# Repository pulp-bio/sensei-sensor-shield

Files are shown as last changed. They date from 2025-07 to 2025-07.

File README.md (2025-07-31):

# SENSEI Sensor Shield

This repository contains the hardware design files for the **SENSEI Sensor Shield**, a versatile extension developed as part of the **Urban Twin** project. The sensor shield integrates multiple sensors for environmental monitoring and is designed to work seamlessly with the [SENSEI Base Board](https://github.com/pulp-bio/sensei-base-board), offering advanced data collection capabilities for urban sensing and other applications.

## Overview

The **SENSEI Sensor Shield** is an extension board designed to support a wide range of sensors for environmental data acquisition. It can be used in urban monitoring scenarios, including air quality monitoring, light sensing, and structural health diagnostics. Developed under the **Urban Twin** project, it is built for flexibility and long-term deployment, making it ideal for multi-sensor applications.

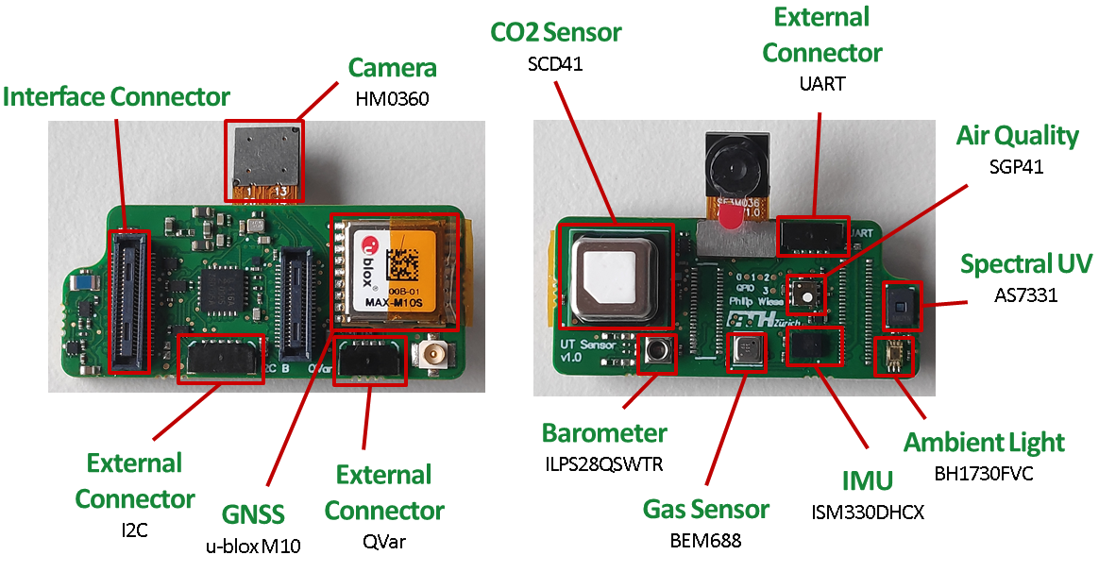
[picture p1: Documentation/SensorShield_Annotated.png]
SENSEI Sensor Shield


### Key Features
- **Optical Sensors**:
  - **Ultraviolet (UVA, UVB, UVC)** sensing.
  - **Infrared and Visual light** sensing.
  - **Camera (HM0360)**: 640 x 480 resolution at 60 fps.

- **Environmental Sensors**:
  - **CO2 Sensor (SCD41)**.
  - **Air Quality Sensor (SGP41)**.
  - **Barometer (ILPS28QSWTR)**.
  - **Gas Sensor (BME688)**.
  - **Quasi-Electrostatic Potential (QVar)** for detecting potential changes.

- **Position/IMU Sensors**:
  - **IMU (ISM330DHCX)**: Advanced 6 DOF sensor for motion tracking and vibration analysis.
  - **GNSS (u-blox M10)** for accurate geolocation.

- **External Connectors**:
  - **I2C, UART**, and **GPIO** for seamless integration of additional peripherals.

### Software Development Kit (SDK)
The **SENSEI SDK** provides software support for both the **SENSEI Base Board** and the **SENSEI Sensor Shield**. It includes sensor drivers, power management, and communication tasks to facilitate data collection and processing. The SDK is available at [SENSEI SDK Repository](https://github.com/pulp-bio/sensei-sdk).

### Demo Applications
- YOLOv5 Occupancy Detection: https://github.com/pulp-bio/sensei-demo-yolov5
- Sensor Readout: https://github.com/pulp-bio/sensei-demo-sensorhub

## Changelog
A detailed changelog is available in the [Changelog.md](Changelog.md) file, which tracks all major updates and revisions to the board's design and documentation.

## Contributors
- **Philip Wiese** ([wiesep@iis.ee.ethz.ch](mailto:wiesep@iis.ee.ethz.ch))
- **Sebastian Frey** ([sefrey@iis.ee.ethz.ch](mailto:sefrey@iis.ee.ethz.ch))

## Publications

If you use the SENSEI Sensor Shield in your work or research, you can cite us with:

### COINS 2025: A Multi-Modal IoT Node for Energy-Efficient Environmental Monitoring with Edge AI Processing
```
@misc{wiese2025multimodaliotnodeenergyefficient,
      title={A Multi-Modal IoT Node for Energy-Efficient Environmental Monitoring with Edge AI Processing},
      author={Philip Wiese and Victor Kartsch and Marco Guermandi and Luca Benini},
      year={2025},
      eprint={2507.14165},
      archivePrefix={arXiv},
      primaryClass={eess.SP},
      url={https://arxiv.org/abs/2507.14165},
}
```
This paper has been accepted at 2025 IEEE International Conference on Omni-layer Intelligent Systems (COINS) and the preprint is available on arXiv @ [arXiv:2507.14165](https://arxiv.org/abs/2507.14165).

### SENSEI Paper
```
TBD
```

## License
This repository makes use of two licenses:
- for all *software*: Apache License Version 2.0
- for all *hardware*: Solderpad Hardware License Version 0.51

For further information have a look at the license files: `LICENSE.hw`, `LICENSE.sw`

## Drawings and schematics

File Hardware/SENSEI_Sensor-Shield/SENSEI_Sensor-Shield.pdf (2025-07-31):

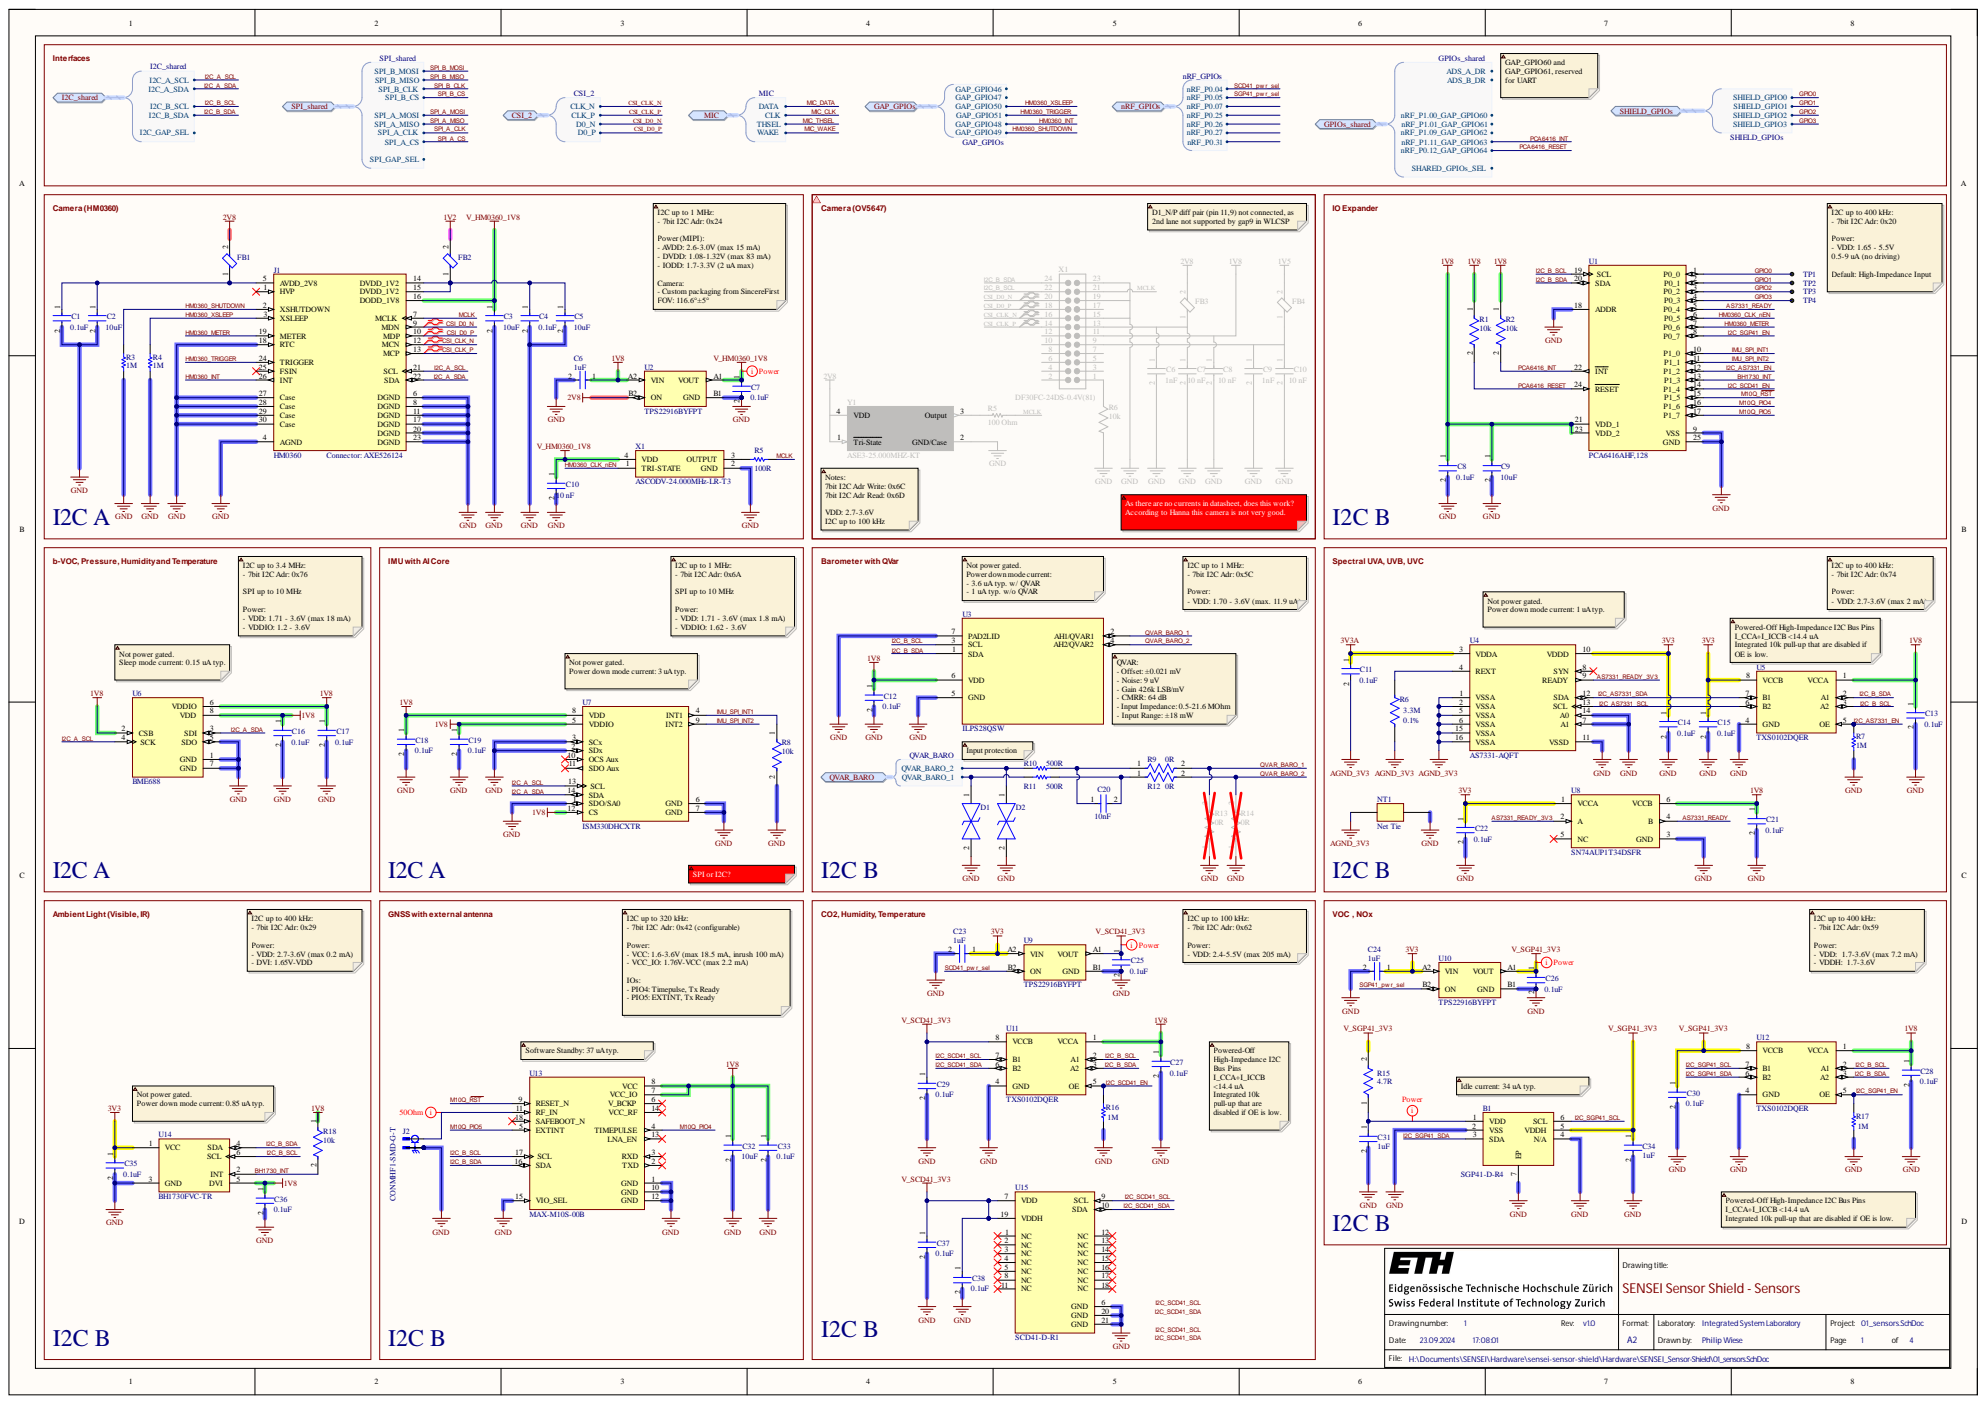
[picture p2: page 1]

D1_N/P diff pair (pin 11,9) not connected, as
2nd lane not supported by gap9 in WLCSP

Default: High-Impedance Input

Camera:
- Custom packaging from SincereFirst
FOV: 116.6°±5°

As there are no currents in datasheet, does this work?
According to Hanna this camera is not very good.

b-VOC, Pressure, Humidityand Temperature

IMU with AI Core

Not power gated.
Power down mode current:
- 3.6 uA typ. w/ QVAR
- 1 uA typ. w/o QVAR

Spectral UVA, UVB, UVC

SPI up to 10 MHz

Power down mode current: 1 uAtyp.

Powered-Off High-Impedance I2C Bus Pins
I_CCA+I_ICCB <14.4 uA
Integrated 10k pull-up that are disabled if
OE is low.

Sleep mode current: 0.15 uA typ.

Power down mode current: 3 uAtyp.

Ambient Light (Visible, IR)

Power:
- VCC: 1.6-3.6V (max 18.5 mA, inrush 100 mA)
- VCC_IO: 1.76V-VCC (max 2.2 mA)

Idle current: 34 uA typ.

Power down mode current: 0.85 uAtyp.

disabled if OE is low.

Integrated 10k pull-up that are disabled if OE is low.

Drawing title:
SENSEI Sensor Shield - Sensors

File:
H:\Documents\SENSEI\Hardware\sensei-sensor-shield\Hardware\SENSEI_Sensor-Shield\01_sensors.SchDoc

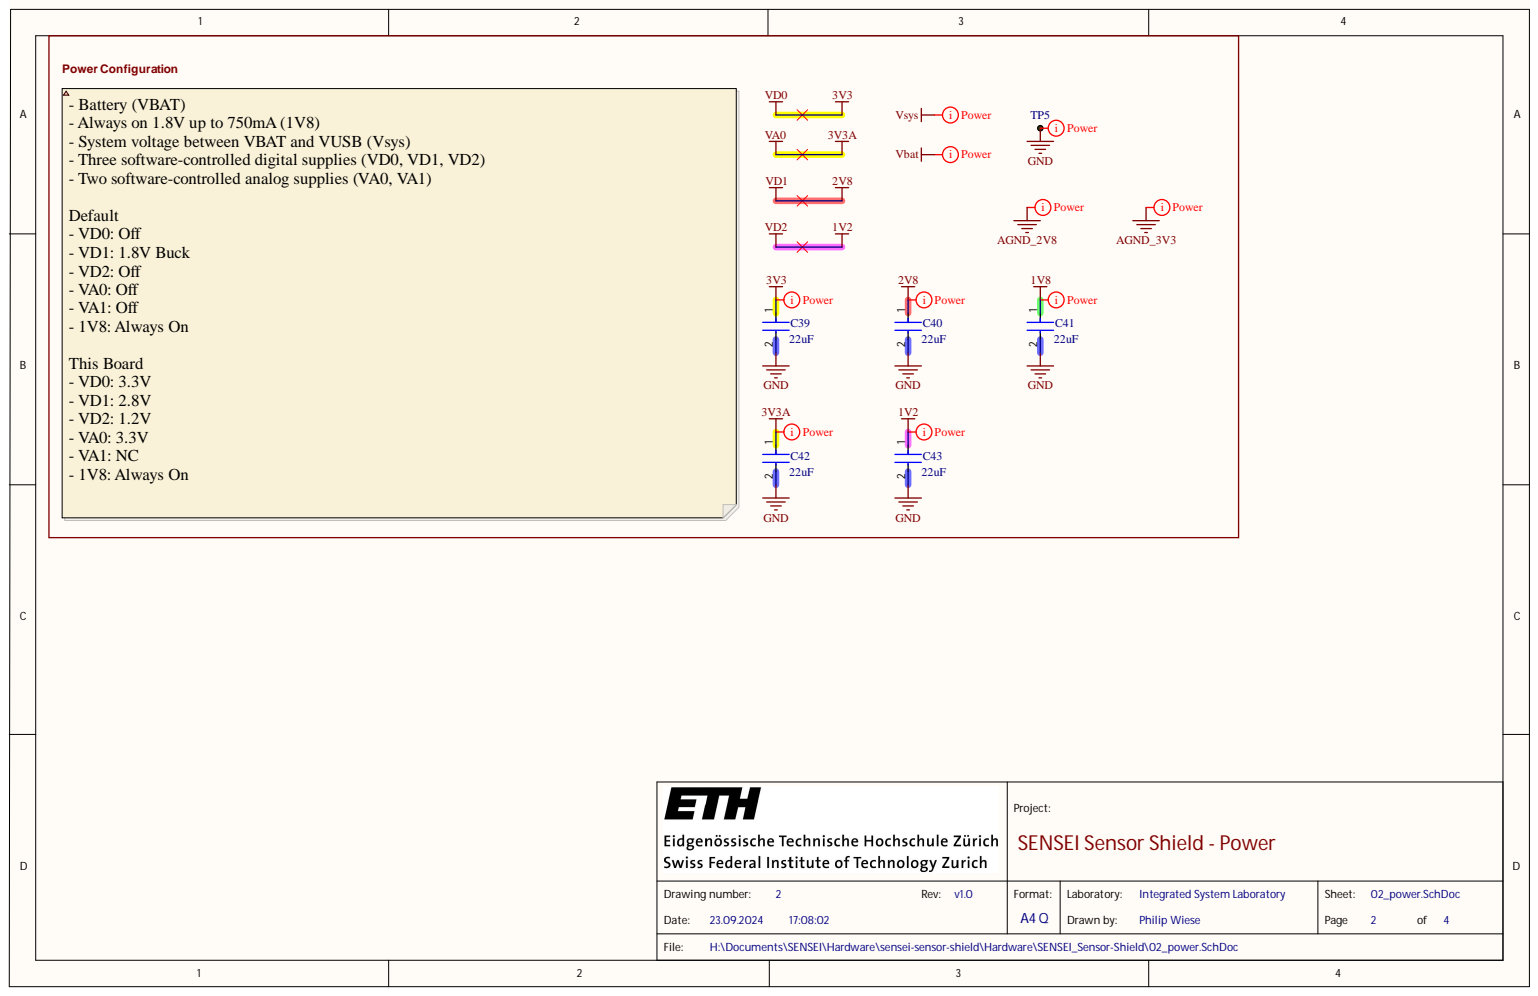
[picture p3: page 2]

- Battery (VBAT)
- Always on 1.8V up to 750mA (1V8)
- System voltage between VBAT and VUSB (Vsys)
- Three software-controlled digital supplies (VD0, VD1, VD2)
- Two software-controlled analog supplies (VA0, VA1)

Project: SENSEI Sensor Shield - Power

Drawing number: 2 Rev: v1.0 Date: 23.09.2024 17:08:02 | Format: A4 Q | Laboratory: Integrated System Laboratory Drawn by: Philip Wiese | Sheet: 02_power.SchDoc Page 2 of 4

H:\Documents\SENSEI\Hardware\sensei-sensor-shield\Hardware\SENSEI_Sensor-Shield\02_power.SchDoc

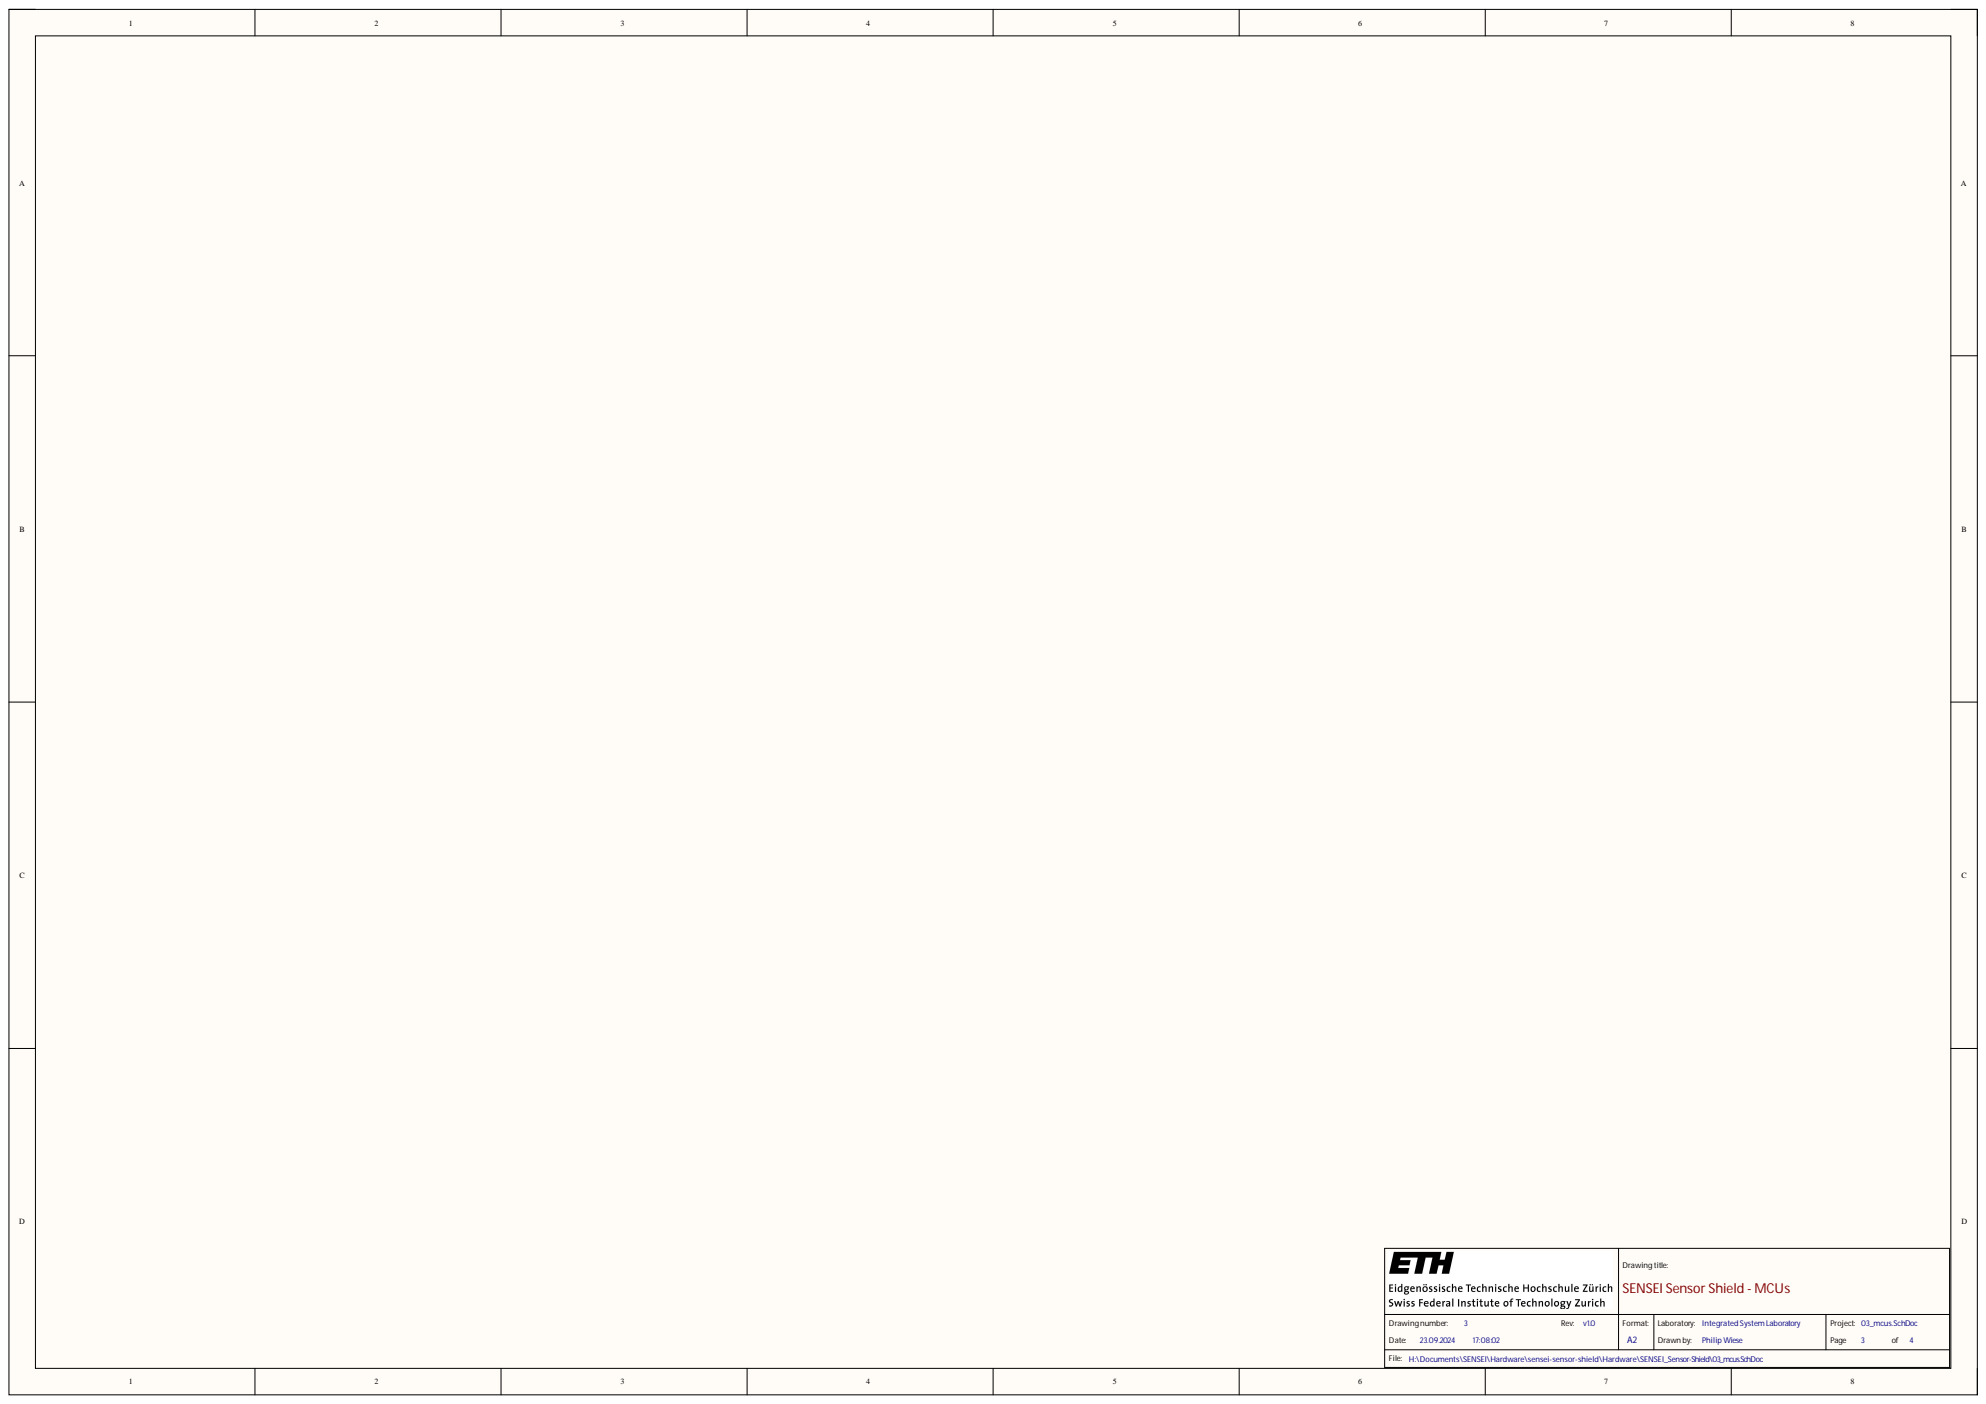
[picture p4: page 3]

Drawing title: SENSEI Sensor Shield - MCUs

17:08:02 | A2 | Laboratory: Integrated SystemLaboratory PhilipWiese | Project: 03_mcus.SchDoc Page 3 of 4

H:\Documents\SENSEI\Hardware\sensei-sensor-shield\Hardware\SENSEI_Sensor-Shield\03_mcus.SchDoc

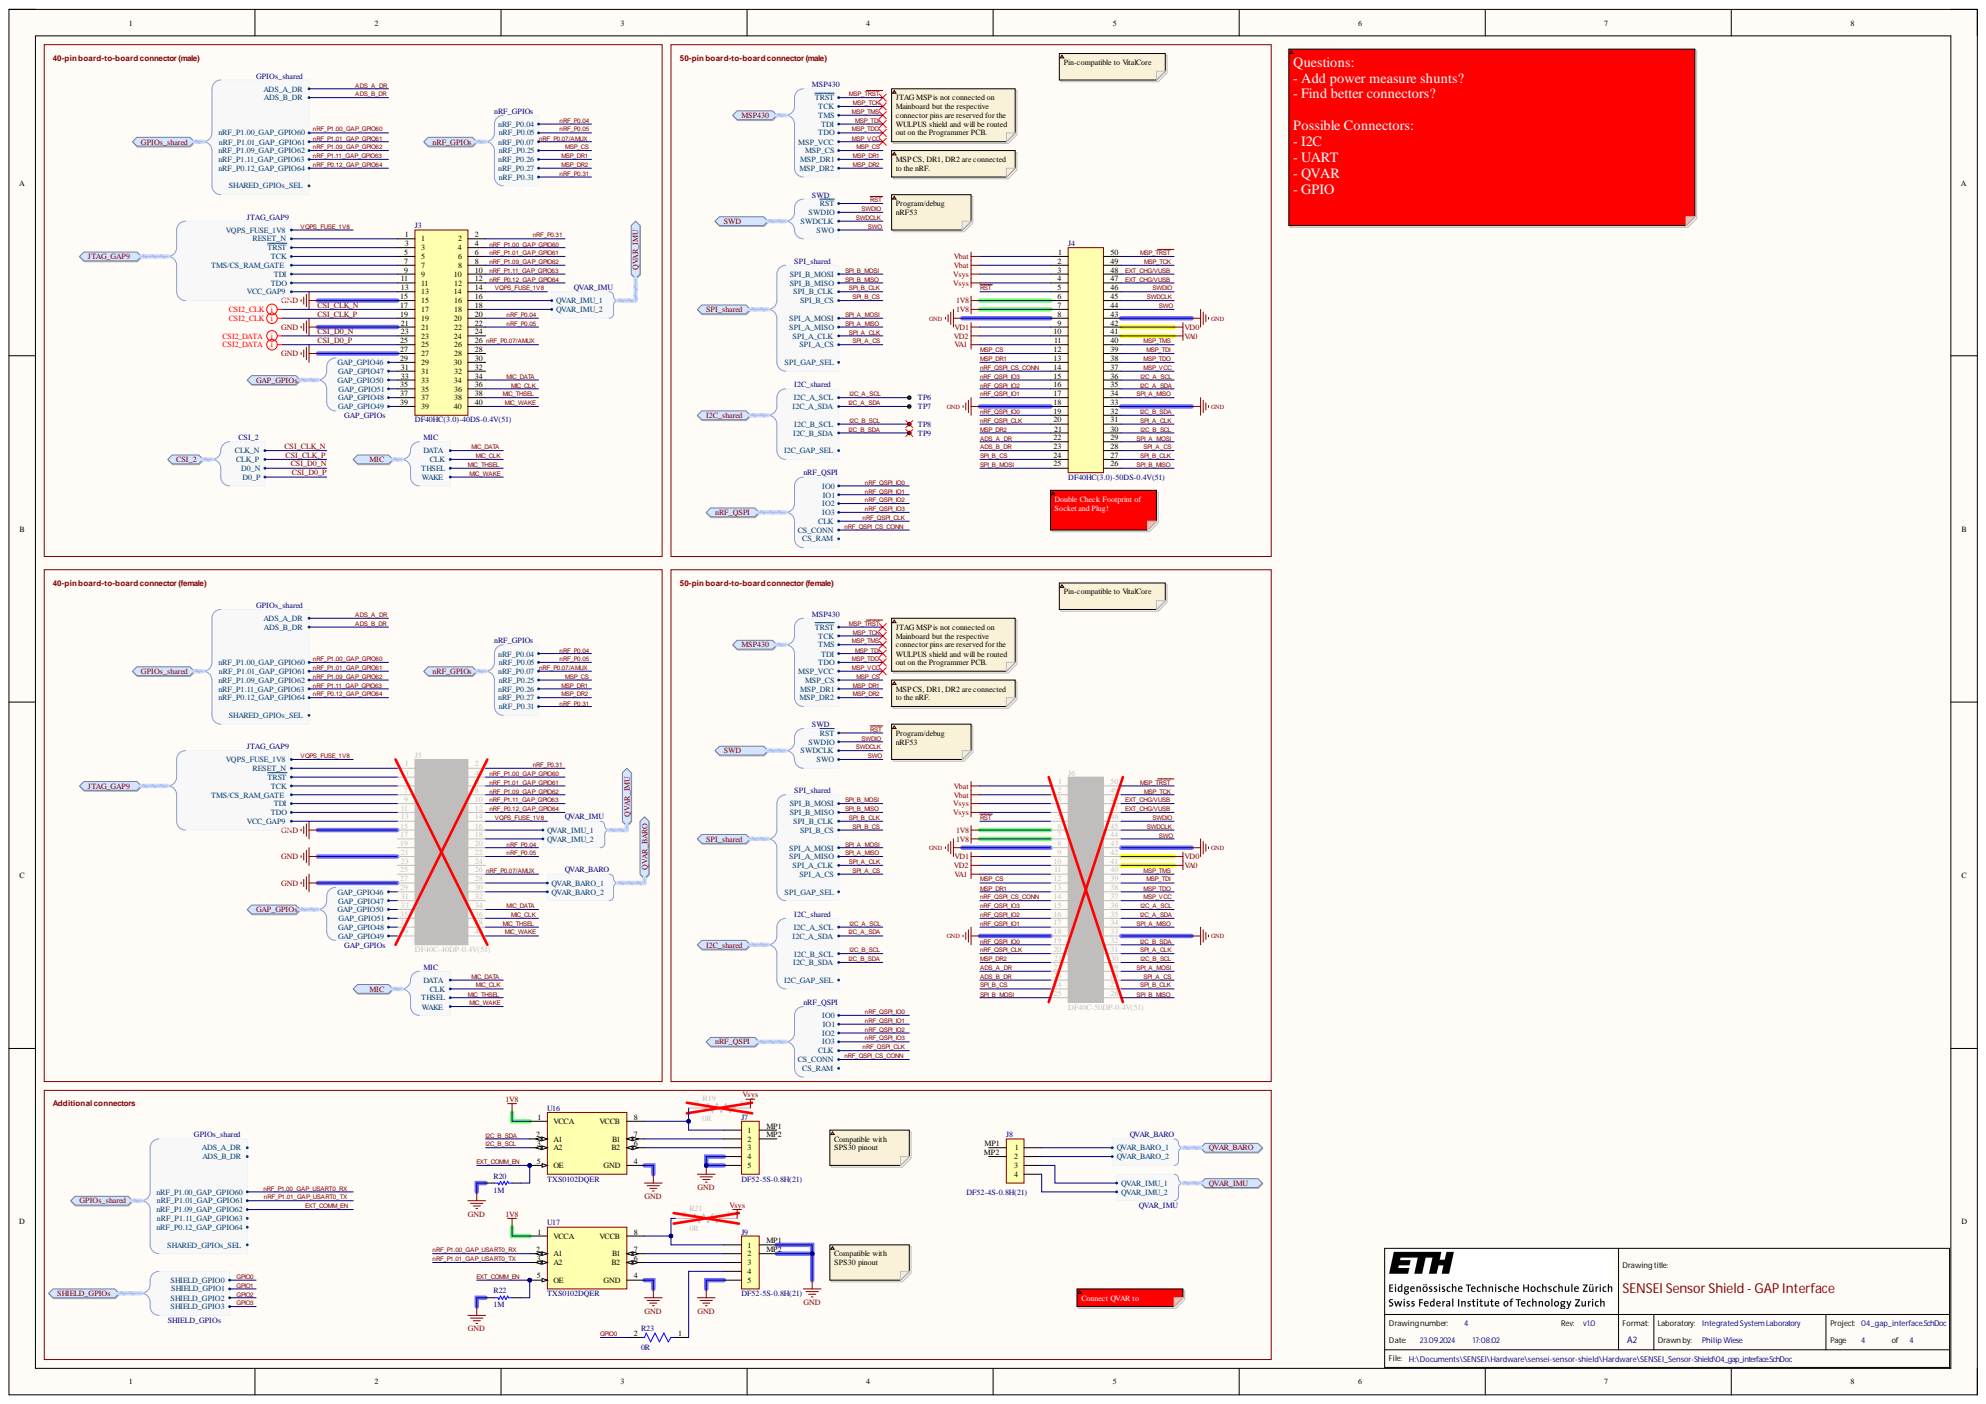
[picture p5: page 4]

40-pin board-to-board connector(male)

50-pin board-to-board connector(male)

Pin-compatible to VitalCore

Questions:
- Add power measure shunts?
- Find better connectors?

JTAG MSP is not connected on
Mainboard but the respective
connector pins are reserved for the
WULPUS shield and will be routed
out on the Programmer PCB.

Double Check Footprint of
Socket and Plug!

Drawing title:
SENSEI Sensor Shield - GAP Interface

H:\Documents\SENSEI\Hardware\sensei-sensor-shield\Hardware\SENSEI_Sensor-Shield\04_gap_interface.SchDoc

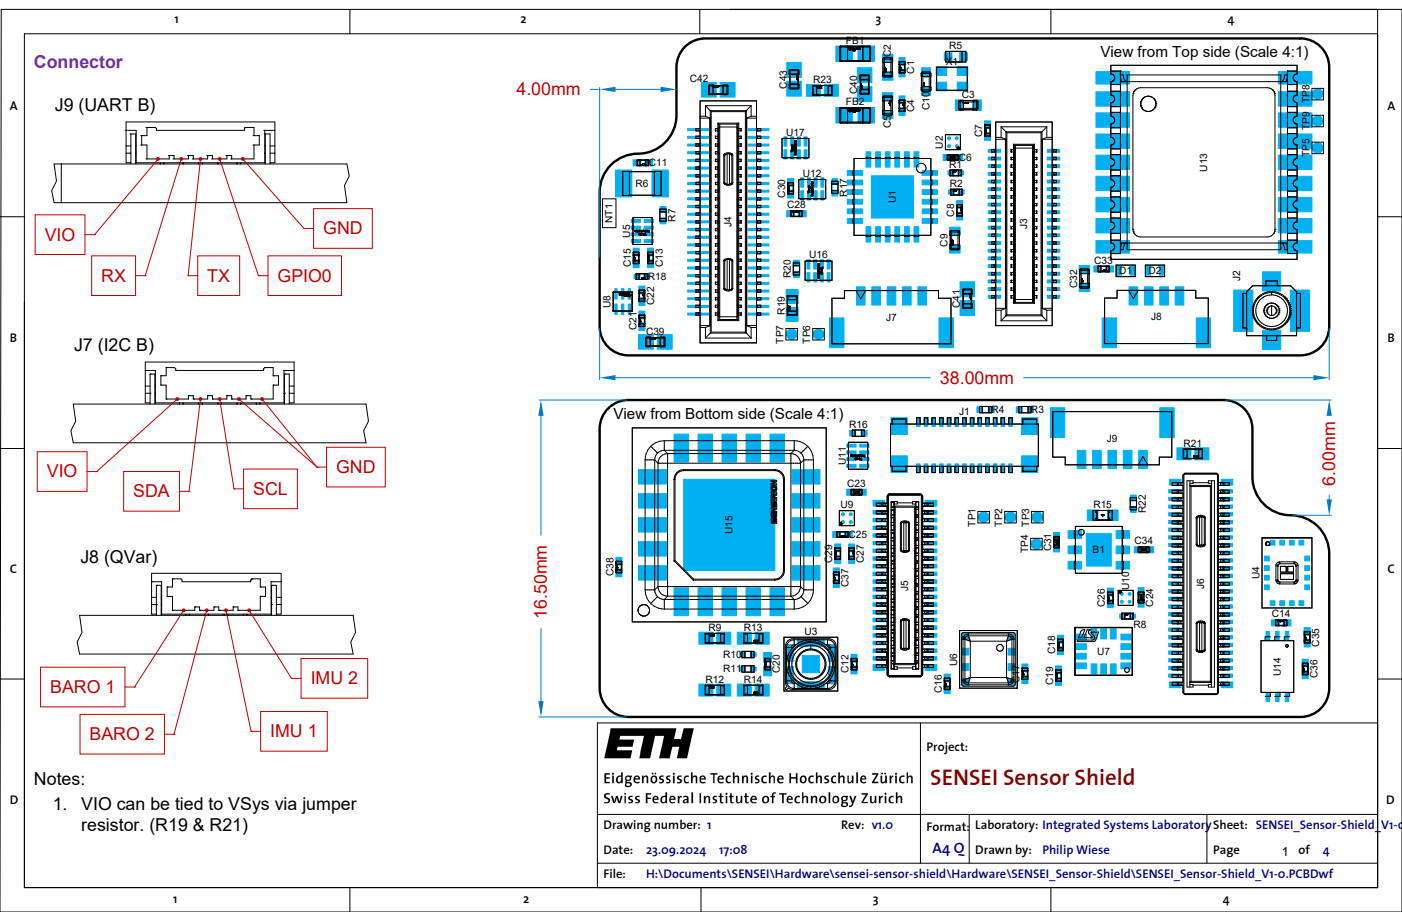
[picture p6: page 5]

View from Top side (Scale 4:1)

View from Bottom side (Scale 4:1)

VIO can be tied to VSys via jumper

Laboratory: Integrated Systems Laboratory

H:\Documents\SENSEI\Hardware\sensei-sensor-shield\Hardware\SENSEI_Sensor-Shield\SENSEI_Sensor-Shield_V1-0.PCBDwf

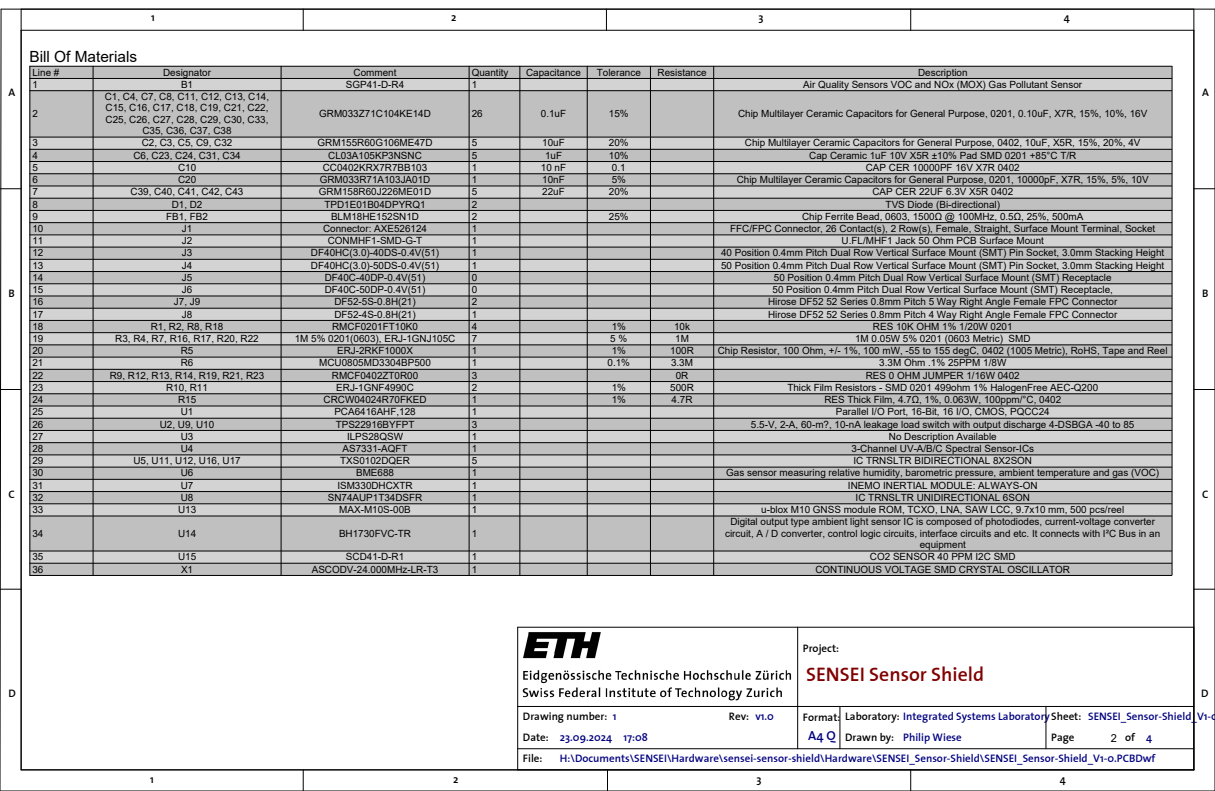
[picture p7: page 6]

Line # | Designator | Comment | Quantity | Capacitance | Tolerance | Resistance | Description
1 | B1 | SGP41-D-R4 | 1 | | | | Air Quality Sensors VOC and NOx (MOX) Gas Pollutant Sensor
2 | C1, C4, C7, C8, C11, C12, C13, C14, C15, C16, C17, C18, C19, C21, C22, C25, C26, C27, C28, C29, C30, C33, C35, C36, C37, C38 | GRM033Z71C104KE14D | 26 | 0.1uF | 15% | | Chip Multilayer Ceramic Capacitors for General Purpose, 0201, 0.10uF, X7R, 15%, 10%, 16V

3 | C2, C3, C5, C9, C32 | GRM155R60G106ME47D | 5 | 10uF | 20% | | Chip Multilayer Ceramic Capacitors for General Purpose, 0402, 10uF, X5R, 15%, 20%, 4V
4 | C6, C23, C24, C31, C34 | CL03A105KP3NSNC | 5 | 1uF | 10% | | Cap Ceramic 1uF 10V X5R ±10% Pad SMD 0201 +85°C T/R
5 | C10 | CC0402KRX7R7BB103 | 1 | 10 nF | 0.1 | | CAP CER 10000PF 16V X7R 0402
6 | C20 | GRM033R71A103JA01D | 1 | 10nF | 5% | | Chip Multilayer Ceramic Capacitors for General Purpose, 0201, 10000pF, X7R, 15%, 5%, 10V
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

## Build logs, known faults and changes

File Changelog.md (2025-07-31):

# Changelog

## Version 1.1 (unreleased)
- 

## Version 1.0 (23.09.24)
- Inital Version

## Version 0.2 - PCB Review (02.04.24)
- [General] Switched to an 8 Layer PCB with more GND planes
- [Via] Switched from 0.1/0.3mm vias to 0.2/0.4mm
- [GPS] Added 50 Ohm single-ended impedance matching for antenna
- [Camera] Connect XShutDown and XSleep directly to GAP9
- [Camera] Connect CLK Enable to IO expander instead of directly to XShutDown
- [Camera] Added load switch to separately control 1.8V
- [Camera] Removed the AGND to make the PCB more feasible
- [Connector] Connected VIO to VSys via zero-ohm resistor (UART & I2C)
- [Board] Increase the vertical board size by 1mm (0.5mm on both sides)

### Open comments
#### Julian
> I see in the datasheet, that you might need to sequence XShutDown and XSleep such that the camera can start up. You can access both pins IOs via GPIOs and expander but if you need the camera a lot, it might be worth adding a sequencer.

I want to try to keep the complexity (number of components and "automation") as low as possible. Hence, I connect XShutDown and XSleep directly to GAP9, which allows proper manual sequencing. In case there is some room for optimization, I will tackle this in the second iteration.

> I see the HM0360_Int and HM0360_trigger are directly connected to gap_gpios, I directly connected only HM0360_trigger and sleep, and the interrupt seemed for me to uninteresting (look at the datasheet if the interrupt pin of the camera really is what you think... for me seemed not...)

I am interested in the ALC (Illumination Change) and MD (Motion Detection) features.

> Why do you use the hm0360_shutdown pin to turn on the external oscillator... in the timing sequence of the camera the clock was already running, I'm not sure if this could lead to troubles if you want to repurpose the shutdown pin for turning on the osci, just check please

Good point! I connect CLK Enable to the IO expander instead of directly to XShutDown. As the default IO configuration is high-impedance input, the clock is on by default.

> For the voltage generation, 2V8, 1v8, and 1v2  usually cameras want you to follow the start-up sequence 2v8, 1v8, and 1v2 but in the hm0360 datasheet the timing between them is 0s, meaning it probably isn't a strict requirement, but I don't see a strict boot sequence from your board so I just wanted to mention this.

2.8V and 1.82 are user-controlled, but I added another load switch to separately control 1.8V.

#### Marco Guermandi 
> Lengths don't seem to be matched. They all should be matched in length to, say, 0.1mm.

Thanks, I somehow forgot that. I added a design rule and matched the length in this version.

> The lanes should be impedance controlled. Is the spacing/width ok for the layer stack you are using to have 100 ohm diff, 50 ohm single ended?

Yes, this is correctly configured.

> The plane under the csi2 lanes should be a clean ground plane with no interruptions to guarantee a good flow of the return currents. The csi2 lanes should never cross signal traces on the layer underneath, at most supplies. If you need to break the ground plane you can use stitching caps but not ideal.

I switched to an 8-layer PCB with more GND planes and removed the AGND for the camera (like Julian did in his design). This also simplified routing.

> Also having an additional connector for the csi2 will degrade signal quality. Is it needed? If yes, it would probably be better to have mounting options or the connector might give significant stubs (ideally, you don't want to have any unterminated portions of the trace or it'll lead to reflections). This will be very bad especially for anything you connect on J5 as you'll have very long stubs on your board

Removed stubs and configured the top connector to not-fitted.

> GNSS antenna should have 50 ohm routing and perhaps better clearance. Maybe adding an optional matching network could be nice? e.g. a pi network.

True, I added a single-ended 50-ohm impedance rule. However, the reference design from uBlox does not show a matching circuit, as the module is supposed to require a minimum number of external components. Hence, I assume it is not required.

> I'm not super expert on QVAR, but shouldn't be there electrodes or something? What's the planned use for it (if any?)

Yes, the idea is that the electrodes can be connected via the connector. For example, to measure some moisture levels, rain, or the proximity to some objects.

> The antenna connector is very close to the module. Depending on the shape of the connector on the antenna, I'm not 100% there'll be enough room for it. Maybe double check on the datasheet of the antenna you're planning to use

I slightly increased the board size, and it should not be a problem, as the size of the U.FL plug is usually not larger than the socket itself.

> The 1.2V to the camera seems like a very thin trace (and camera draws quite a bit, the sch says 83 mA?). I think the other supplies look fine but maybe I missed some so please double check.

I did increase the trace width.

> I see the vias are all tented. If you think some signals are worth having some quick access points for debug, leaving some (or even all) without soldermask on could be a good idea for the first release of a board.

I did configure some of the vias to be not tented. However, this excludes vias that are beneath components and the ones where the net is easily accessible on a bigger component.

> The clearance vs the adjacant lanes is quite low, it'll affect the impedance and create discontinuities. A bit more would be better. For some reference on csi2 routing https://www.ti.com/lit/an/spracp4/spracp4.pdf gives ideas on clearances and general routing strategies

Thanks for the great reference. I tried to increase the clearance (0.2mm to GND and 0.4mm to other nets), but there is just not that much space, especially in the connector.

## Version 0.1 - Shematics Review (27.02.24)
- [Camera] Switched from `AXT526124` to `AXE526124`
- [Camera] Swichted from 1nF and 10nF to 100nF and 10uF capacitors
- [IO Expander] Swichted from 1nF and 10nF to 100nF and 10uF decoupling capacitors
- [Connector] Changed external connector from Pico-EZmate to DF52
- [UV Sensor] Connect power of U7
- [UV Sensor] Swichted from 10nF to 100nF decoupling capacitors
- [UV Sensor] Added 100nF decoupling capacitors to U4
- [SCD41] Added 100nF decoupling capacitors to U12
- [SCD41] Added 100nF decoupling capacitors to U13
- [SGP41] Switched to 3V3 power supply
- [SGP41] Added I2C Isolation
- [GPS] Swichted from 1uF to 10uF decoupling capacitors
- [IO Expander] Switched from TCA9539RTWR to PCA6416AEVJ due to smaller package
- [IMU] Added pull-down to INT1 according to DS
- Marked I2C pull-ups as not fitted.
- Added (not fitted) 22uF decoupling caps to 1V8, VD0, VD1, VD2, VA0

### Open comments
> U6: For the IMU, I suggest using SPI. It is easier to handle high sample rates over SPI than I2C.

For now I use I2C and we switch to SPI in the next iteration if required

> U10: QUestions -> I2C/uart: is fine, expose: yes if possible,  VCC_RF + RF_IN, i'm not sure how active antennas work but i have the impression that if you have VCC_RF on the antenna line the device will see no RF signal. If this is not the case, maybe you can have a jumper connecting these lines.

- For now do not add circuitry for an active antenna
- Use TP for UART

> General: If possible, I will add some 1ohm resistors for the most essential devices.

Not sure if this is a good idea due ot the voltage drop

> General: note that I2C_A has fewer devices connected than I2C_B; you could try to balance the number of connected devices.

The idea is that I2C_A can support up to 1MHz

## Tips for Future
- Instaed of using DF52 use board-to-board connector.
- Use low SGP use 1.8V with switch (e.g. TMUX1112) or 3V3 which might improve performance
